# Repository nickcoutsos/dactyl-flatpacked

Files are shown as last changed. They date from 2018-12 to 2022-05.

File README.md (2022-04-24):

# dactyl–flatpacked

A reimagined [dactyl](https://github.com/adereth/dactyl-keyboard) using 2D
slotted pieces instead of 3D printing.

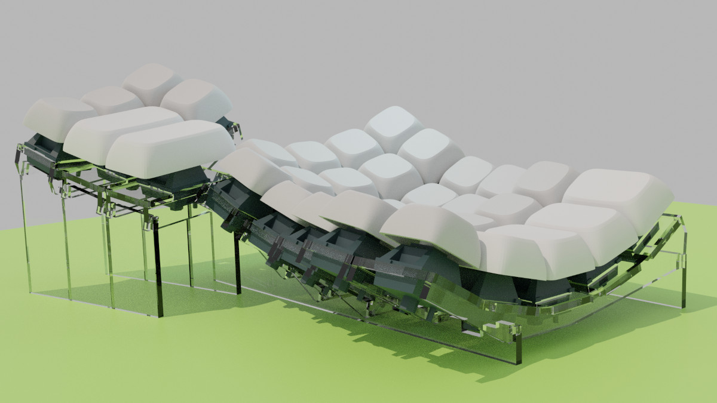
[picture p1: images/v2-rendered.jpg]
Keyboard

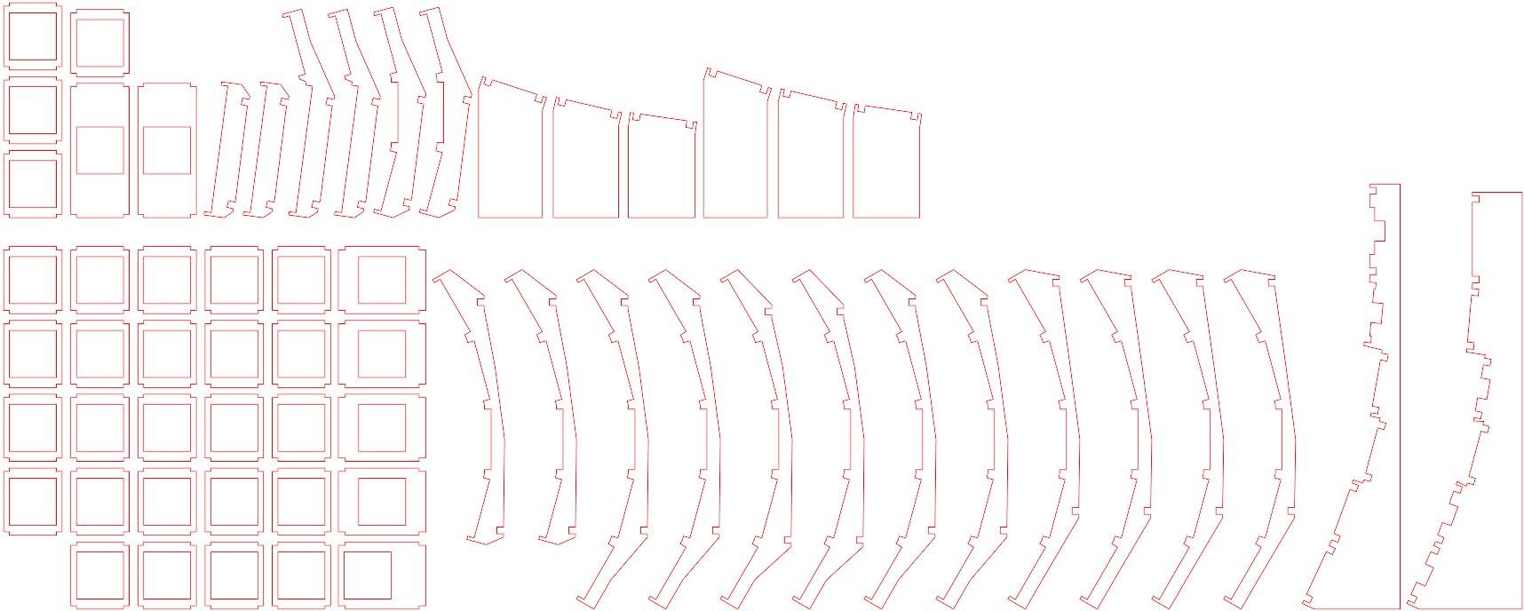
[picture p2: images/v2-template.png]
Cutting template


**Note:** I built this keyboard years ago with code that has since changed
considerably. The current state of the master branch is still a work in progress
and hasn't been tested. I don't have immediate plans to build a new keyboard
from this design in the near future but the refactor and redesign is a fun
project anyway, and hopefully of some use/interest to you.

If you want to see the original code and cutting template look at the tag
`original`.

## The Idea

Use two dimensional pieces of laser cut acrylic, slotted together orthogonally,
to create the Dactyl keyboard shape.

When I started this project the cost to have a Dactyl printed by a third party
seemed prohibitively expensive and the printer I had access to was not up to the
challenge. Neither of these restrictions are true today but this was pretty fun
to work on anyway.

## Recent Changes

This iteration still makes the Dactyl keyboard shape but there are significant
differences:

1. Place column supports on either side of the switch instead of beneath it.
    This requires thinner material but the original 3mm of acrylic was already
    more than thick enough. The current design is 2mm and things seem to fit
    together nicely.
2. Fix the row/column radius calculations to account for keycap height: the
    `mount_width`/`mount_depth` parameters need to reflect the dimensions of the
    keycap at its base in order to get the correct spacing.
3. Construct everything from extruded polygons instead of `hull()`ing and
    `difference()`ing all kinds of geometry. This seems to perform better and
    makes it less weird to try to flatten everything when generating a cutting
    template (which is kind of the whole point anyway).

To simplify the code I've started migrating things over to using the amazing
[BOSL2](https://github.com/revarbat/BOSL2) library.

## See Also

Over time I have seen more designs pop up using similar ideas to build up the
structure of a 3D contoured keyboard using 2D laser cut components. You may be
interested in looking at:

* [Habilis](https://github.com/thblt/habilis) by Thibault Polge
    * Designed in Autodesk Inventor, I think
    * This is the first implementation I saw after my own
    * It seems to have the most in common with the dactyl-flatpacked
    * Pictures available on his reddit posts:
        * [/r/MechanicalKeyboards/comments/cbehge/very_early_preview_my_first_build_a/](https://www.reddit.com/r/MechanicalKeyboards/comments/cbehge/very_early_preview_my_first_build_a/)
        * [/r/MechanicalKeyboards/comments/cm97ey/my_first_build_the_habilis_design_preview_while/](https://www.reddit.com/r/MechanicalKeyboards/comments/cm97ey/my_first_build_the_habilis_design_preview_while/)
        * [/r/MechanicalKeyboards/comments/covxon/first_real_prototype_for_my_split_concave_build/](https://www.reddit.com/r/MechanicalKeyboards/comments/covxon/first_real_prototype_for_my_split_concave_build/)
* [Acrylic 3D KB](https://github.com/kobababa/Acrylic_3D_KB) by Kobakos
    * Designed in Fusion 360
    * I was really impressed by the elegance of this design.
    * It does sacrifice curvature around the Y axis and per-column stagger, but
        I think grouping pairs of columns is a clever compromise and results in
        a much smaller part count.
    * Having fewer and larger pieces would help with assembly and probably makes
        for a less fragile end result.
* [Lasercut modular ergo keyboard with wells](https://www.reddit.com/r/ErgoMechKeyboards/comments/njuay2/second_prototype_of_a_lasercut_modular_ergo/) by [/u/Macone4](https://www.reddit.com/user/Macone4)
    * Designed in Fusion 360
    * Also [the first prototype post](https://www.reddit.com/r/ErgoMechKeyboards/comments/nbbqdz/first_proof_of_concept_of_a_lasercut_modular/)
    * Tighter curvature than the Dactyl, I think
    * First time seeing one of these using wood!
    * Looks to be a similar strategy to the dactyl-flatpacked and Habilis
    * A single support down the center of each column is interesting
        * May allow columns to squeeze in more tightly without interference
        * Looks like this would add to the minimum height due to the extra
            clearance needed underneath the switch
* [Laser cut dactyl](https://www.reddit.com/r/ErgoMechKeyboards/comments/txumq3/laser_cut_dactyl/) by [Rannathrtv](https://www.reddit.com/user/Rannathrtv)
    * Designed in Fusion 360
    * Another wooden design, the end result looks lovely with the burnt edges!
    * Row-based instead of column based, so curvature is around X axis and is
        otherwise ortholinear
    * Far fewer pieces to deal with
    * May have been designed with hotswap sockets in mind
    * Based on images it looks like there is a slight tenting so the row pieces
        don't technically slot in at 90˚. This may not be an issue if everything
        is glued or otherwise held firmly in place.

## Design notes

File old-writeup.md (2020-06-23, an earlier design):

# dactyl–flatpacked

A reimagined [dactyl](https://github.com/adereth/dactyl-keyboard) using slotted
rib pieces to create the countoured surface instead of a solid 3D printed part.

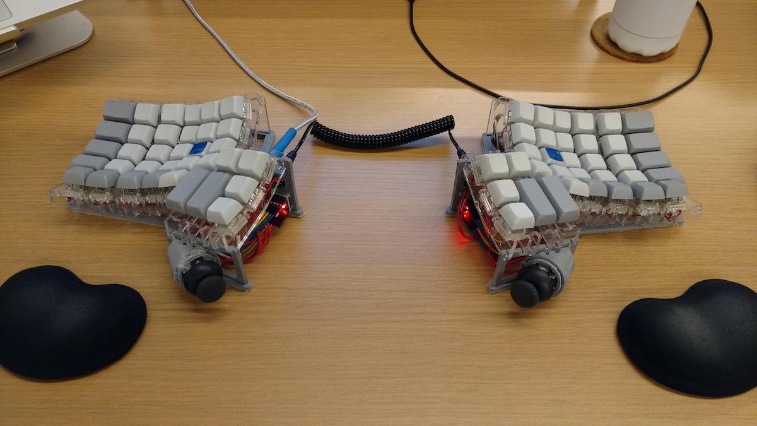
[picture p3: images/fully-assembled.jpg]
Keyboard

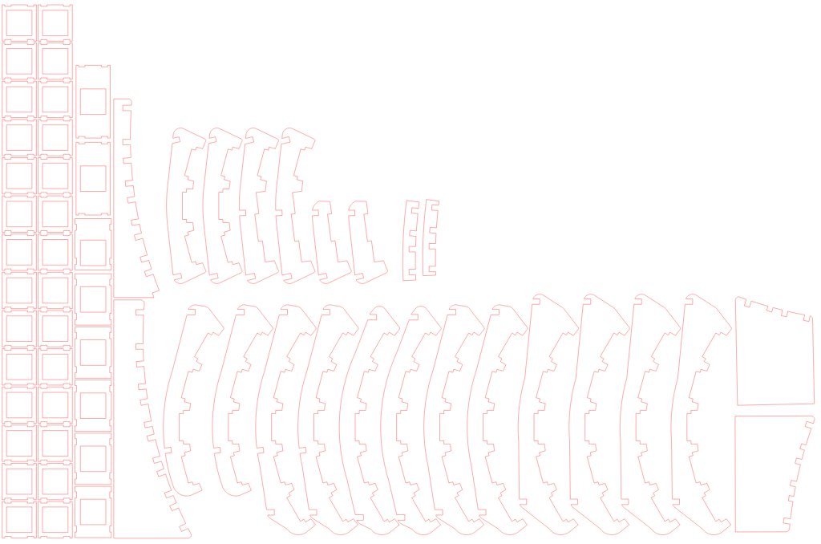
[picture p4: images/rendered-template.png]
Cutting template


**Note:** the current state of the master branch doesn't accurately reflect the
version of the keyboard that I have built. Since then I've started to work on a
low profile version and have refactored most of the code as well as re-designed
the rib pieces and thumb cluster. Check out the tag _original_ to see more or
less the original code used to generate the initial laser cut template.

## Inspiration

When I first head about the dactyl keyboard I had been realizing that my typing
habits have been awful for years despite being able to type quickly and with few
mistakes. The dactyl seemed to address a lot of the problems but seemed like a
big investment to either order quality printed parts or to attempt printing it
myself.

Rather than spend moeny directly on something I may not have actually enjoyed in
the end, I decided to try creating a design that could match the original
contours using many smaller pieces that could be reliably cut from wood or
acrylic. The time to design and assemble the structure myself was likely more
expensive but the experience was invaluable.

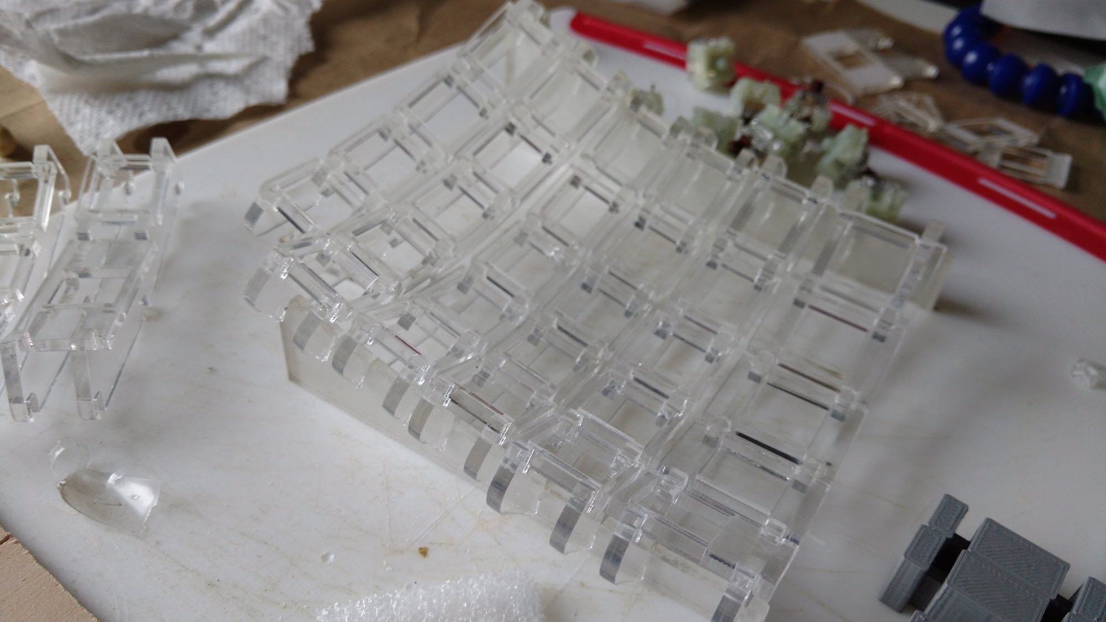
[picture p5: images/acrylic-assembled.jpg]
assembled


## Execution

The first step was rewriting the positioning code in OpenSCAD directly. Clojure
is interesting, OpenSCAD is... flawed, but the pipeline of _lein_ to _clojure_
to _scad-clj_ to _OpenSCAD_ was a lot of trouble and made debugging painful.

Once I had OpenSCAD code that matched the original layout I could throw most of
the rest of the code away; I didn't need to create a 3d printable plate or case
or anything, the rest was from scratch.

I designed curved supports for each column of keys with slots at the front and
back allowing each column to connect to a common front and back row support. The
shorter finger and thumb columns don't reach the row supports and instead use a
small support connecting it directly to the adjacent column.

With the design finished I created another file to import each part rib support,
cross support, an key plate, transformed to be co-planar with the XY plane, and
projected to a number of 2D shapes. I exported the result to SVG from OpenSCAD
and moved to Inkscape to clean up the result before passing along to a local
company for laser cutting.

## Wiring and Programming

> TODO, add more details and pictures here

Wiring was painful. I think I could have gotten away with thinner and shallower
rib pieces that would've made it easier to get in with my soldering iron. My
design included small gaps that I hope would allow me to snake magnet wire along
each row of switches, but that didn't work out. I had the idea to run ribbon
cables down each column to connect the rows in a more convoluted way which was a
mess but it worked. If I did this before gluing all of the columns to the cross
supports I might have had an easier time but overall I think it woulve been
smarter just to run wires across the columns and be done with it.

The firmware wasn't anything terribly special. I copied the dactyl manuform code
from the QMK repo and modified it to match the physical layout of the original
dactyl. This was obnoxious because I had to hardcode changes that ideally could
have been configuration (the physical layout of the dactyl, but the manuform's
use of two pro micros instead of a teensy and IO expander).

## Results

I've been using my dactyl keyboard at work for several months now and quite like
it. The way I describe it to other people is:

> The keys are where my fingers want to be.

It's hard to say how much of this is unique to the dactyl design or specifically
which aspects of the design. The main features I'll harp on is column-stagger
instead of row-stagger and, by extension, column depth offsets to match (partly)
different lengths of finger.

A few issues:

### Thumb Cluster

There are keys that I don't really care to reach, which is fine for toggles, I
guess, but I also feel that the 2h keys use up valuable space. It's nice that
there are cheap ergodox keysets readily available to use in my keyboard but if I
were to do it again I'd work on making things more compact.

### Gaps Between Keys

I think this is my own fault. The original dactyl was designed for SA keycaps
which are significantly taller than the XDA profile I chose. This is a problem
because much of the calculations for key positioning are based on the height of
the keys and the height (thickness) of the plate. Taller keys need a higher
radius to fit in the same curve which means my keys end up spaced out. This is
one of the areas where the dactyl code could be better documented.

Unfortunately I'm realizing that had I worked off of the dactyl manuform fork I
might have been able to better understand these details and account for them.
The manuform fork seems to use very clear variable names and introduces even
more for better configurability.

### Height

This is possibly my biggest gripe.

This is kind of the nature of the beast of a non-flat keyboard layout. With the
degree of curvature and the minimum height for the lowest keys (this includes
the combined height of the keycap and keyswitch, down to the electrical contacts
underneath) you end up with a keyboard that is significantly taller than, say, a
typical Apple bluetooth keyboard. On top of my desk I need to raise my wrists
quite a bit so that my hands can hang downward. A better solution is to put the
keyboard on a lowered tray, or make sure your chair can be comfortably raised
high enough to compensate.

## Next Up

I'm working on a redesign using kailh low profile switches and keycaps, with a
reduced curvature on the main cluster. This should help keep the keyboard height
reasonable. It also redesigns the thumb cluster using 1u keys and increases the
curve so that the innermost keys end up being more vertical, hopefully making
the outer thumb columns easier to reach.

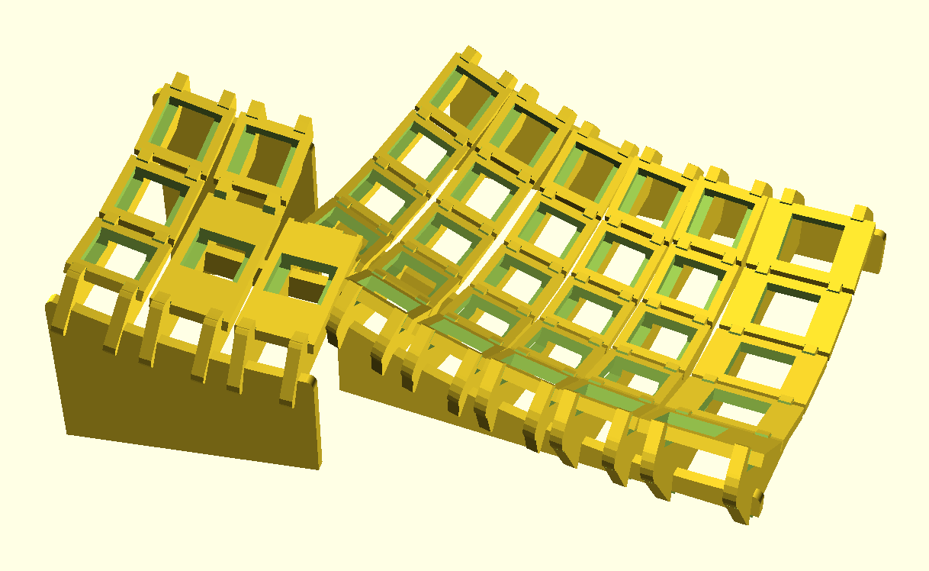
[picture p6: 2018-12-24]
images/rendered-frame.png

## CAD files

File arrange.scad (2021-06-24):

include <BOSL2/std.scad>

function calculate_bounding_box (points_or_region) = (
  let(points = (
    is_path(points_or_region[0])
      ? flatten(points_or_region)
      : flatten(flatten(points_or_region))
  ))
  let(x = [ for(v=points) v.x ])
  let(y = [ for(v=points) v.y ])
  let(min_ = [min(x), min(y)])
  let(max_ = [max(x), max(y)])
  [min_, max_, max_ - min_, (max_ + min_) / 2]
);

function arrange(regions, direction="row", spacing=0, align_items="center") = (
  assert(direction == "row" || direction == "row-reverse" || direction == "column" || direction == "column-reverse")
  assert(align_items == "center" || align_items == "start" || align_items == "end")
  let(bounding_boxes = [ for(r=regions) calculate_bounding_box(r) ])

  let(is_reversed = direction == "row-reverse" || direction == "column-reverse")
  let(is_row = direction == "row" || direction == "row-reverse")

  let(main_axis_component = is_row ? 0 : 1)
  let(main_axis = (is_row ? [1, 0] : [0, 1]))
  let(main_length = sum([
    for(box=bounding_boxes)
    box[2][main_axis_component]
  ]) + spacing * (len(regions)-1))

  let(cross_axis_component = is_row ? 1 : 0)
  let(cross_axis = is_row ? [0, 1] : [1, 0])
  let(cross_length = max([
    for(box=bounding_boxes)
    box[2][cross_axis_component]
  ]))

  let(total_bounding_box = (
    main_axis * main_length +
    cross_axis * cross_length
  ))

  flatten([
    for(i=[0:len(regions)-1])
    let(paths = regions[i])
    let(size = bounding_boxes[i][2])
    let(center = bounding_boxes[i][3])
    let(prev_group_sizes = i == 0 ? 0 : sum([
      for(j=[0:max(0, i-1)])
      bounding_boxes[j][2][main_axis_component] + spacing
    ]))
    let(main_offset = (
      (size/2)[main_axis_component]
      - (total_bounding_box/2)[main_axis_component]
      + prev_group_sizes
    ))

    let(cross_offset = align_items == "center" ? 0 : (
      (align_items == "start" ? -1 : 1) * (
      (size/2)[cross_axis_component]
      -(total_bounding_box/2)[cross_axis_component]
    )))
    let(offset_ = -center - (cross_axis * cross_offset) + main_axis * (
      is_reversed
        ? total_bounding_box[main_axis_component] - main_offset
        : main_offset
    ))
    [ for(path=paths) move(offset_, path) ]
  ])
);

/**
 * Arrange regions using a CSS flexbox-like rules.
 *
 * Some terminology first:
 *  - a path is an array of vertices ([ [x, y], ... ])
 *  - a region is an array of paths ([[ [x, y], ... ]])
 *
 * This module will arrange and render regions along an axis with the specified
 * alignment and spacing.
 *
 * Given a direction of "row" these regions will be laid out end-to-end (plus
 * "spacing" between eeach) on a "main-axis" going from left to right (x-axis),
 * and vertically aligned on the "cross-axis" (y-axis). Specifying "column" will
 * swap the main and cross axes. Including "-reverse" will lay the regions out
 * in reverse order on the main-axis.
 *
 * By default, regions will be centered on the cross-axis, but can be aligned to
 * the low or high end of the overall bounding box by settign align_items to
 * "start" or "end" respectively.
 *
 * Lastly "anchor" can be used to shift the origin relative to the regions'
 * overall bounding box.
 *
 * These arrangements may also be nested by supplying an array of arrange()'d
 * values.
 *
 * @param <array> regions
 * @param <string> [direction="row"] - one of (row|row-reverse|column|column-reverse)
 * @param <number> [spacing=0] - spacing between bounding boxes of regions
 * @param <string> [align_items="center"] alignment on cross-axis
 * @param <vector[x,y]> anchor
 */
module arrange(regions, direction="row", spacing=0, align_items="center", anchor=[0, 0]) {
  assert(direction == "row" || direction == "row-reverse" || direction == "column" || direction == "column-reverse");
  assert(align_items == "center" || align_items == "start" || align_items == "end");

  arranged = arrange(
    regions,
    direction=direction,
    spacing=spacing,
    align_items=align_items
  );

  box = calculate_bounding_box(arranged);
  size = box[2];
  center = box[3];

  offset_ = [
    -anchor.x * size.x/2,
    -anchor.y * size.y/2
  ];

  translate(-center + offset_)
    region(arranged);
}

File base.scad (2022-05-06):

use <supports.scad>
use <util.scad>
include <definitions.scad>
include <BOSL2/beziers.scad>

// Using `cross_support_bottom_points()` can give us all of the contact points
// of a cross support on the XY plane. From this we can define the paths to cut
// holes out of a base for the keyboard.
//
// What this function actually returns is the bottom profile of a cross support
// which includes the new corner notch cutouts, so the "true" bottom points are
// just the ones where p.z == 0. This does assume that the cross support will
// only have cutouts in the corner, so that the remaining points will be the
// start and end points of the cross support.

xy = function (p) [p.x, p.y];
is_base = function (p) p.z == 0;

thumb_back = [for(i=[0:len(thumb_columns)-1]) map(xy, filter(is_base, cross_support_bottom_points("thumb", "back", i)))];
thumb_front = [for(i=[0:len(thumb_columns)-1]) map(xy, filter(is_base, cross_support_bottom_points("thumb", "front", i)))];
thumb_points = concat(thumb_back, thumb_front);

finger_back = map(xy, filter(is_base, cross_support_bottom_points("finger", "back")));
finger_front = map(xy, filter(is_base, cross_support_bottom_points("finger", "front")));
finger_points = [finger_back, finger_front];

cross_support_holes = [
  for(line=concat(
    thumb_back,
    thumb_front,
    [finger_back,
    finger_front]
  ))

  thicken_line(line, plate_thickness)
];

function inner_round (points, r) = (
  let(inset = offset(points, closed=true, r=-2*r))
  offset(inset, closed=true, r=r)
);

finger_cluster_cutout = inner_round(hull_points(flatten(finger_points)), r=4);
thumb_cluster_cutout = inner_round(hull_points(flatten(thumb_points)), r=4);

outline = concat(
  [finger_back[1]],
  bezier_curve(flatten([
    bez_begin(finger_back[0], 270, 80),
    bez_end(thumb_back[2][0], 0, 0),
  ])),
  [thumb_front[2][0]],
  bezier_curve(flatten([
    bez_begin(thumb_front[0][1], 0, 0),
    bez_end(finger_front[1], 180, 90),
  ]))
);

module base() {
  linear_extrude(height=plate_thickness)
  region(concat(
    [offset(outline, r=4, closed=true)],
    cross_support_holes,
    [finger_cluster_cutout, thumb_cluster_cutout]
  ));
}

color("red") stroke(cross_support_holes, width=0.25, joint_width=0, hull=false);
color("red") stroke(finger_cluster_cutout, width=0.25, joint_width=0, closed=true, hull=false);
color("red") stroke(thumb_cluster_cutout, width=0.25, joint_width=0, closed=true, hull=false);
color("yellow", alpha=0.3) base();

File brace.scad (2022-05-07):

include <BOSL2/std.scad>
include <BOSL2/beziers.scad>
include <definitions.scad>
use <supports.scad>

xy = function (p) [p.x, p.y];
is_base = function (p) p.z == 0;

thumb_back = [for(i=[0:len(thumb_columns)-1]) map(xy, filter(is_base, cross_support_bottom_points("thumb", "back", i)))];
thumb_front = [for(i=[0:len(thumb_columns)-1]) map(xy, filter(is_base, cross_support_bottom_points("thumb", "front", i)))];
thumb_points = concat(thumb_back, thumb_front);

finger_back = map(xy, filter(is_base, cross_support_bottom_points("finger", "back")));
finger_front = map(xy, filter(is_base, cross_support_bottom_points("finger", "front")));
finger_points = [finger_back, finger_front];


function thumb_outer_column_end() = (
  let(
    u = plate_thickness,
    col = thumb_back[2],
    a=col[0],
    b=col[1],
    v=unit(b-a),
    n=line_normal(col)
  )
  [
    a + n*u/2 - v*u,
    a - n*u/2 - v*u,
  ]
);

function thumb_columns () = (
  flatten([
    for (col=reverse(thumb_back))
    let(
      u = plate_thickness,
      a = col[0],
      b = col[1],
      v = unit(b-a),
      n=line_normal(col)
    )
    [
      a - n*u/2,
      a + n*u/2,
      b + n*u/2,
      b - n*u/2,
    ]
  ])
);

function thumb_inner_column_end() = (
  let(
    u = plate_thickness,
    col = thumb_back[0],
    a=col[0],
    b=col[1],
    v=unit(b-a),
    n=line_normal(col)
  )
  [
    b - n*u/2 + v*u,
    b + n*u + v*u
  ]
);

function finger_front_slot() = (
  let(
    finger = finger_front,
    u = plate_thickness,
    p = finger[0],
    v = unit(finger[1] - finger[0]),
    n = line_normal(finger)
  )
  [
    p - n * u/2 + v * 10,
    p - n * u/2,
    p + n * u/2,
    p + n * u/2 + v * 4
  ]
);

function finger_back_slot() = (
  let(
    u = plate_thickness,
    finger = finger_back,
    p = finger[0],
    v = unit(finger[1] - finger[0]),
    n = line_normal(finger)
  )
  [
    p - n * u/2 + v * 4,
    p - n * u/2,
    p + n * u/2,
    p + n * u/2 - v * u,
  ]
);

function finger_to_thumb_curve() = (
  let(
    u = plate_thickness,
    thumb = thumb_back[2],
    tp = thumb[0],
    tv = unit(thumb[1] - thumb[0]),
    tn = line_normal(thumb),
    finger = finger_back,
    fp = finger[0],
    fv = unit(finger[1] - finger[0]),
    fn = line_normal(finger)
  )
  bezier_curve(flatten([
    bez_begin(fp + fn * u/2 - fv * u, 270, 80),
    bez_end(tp + tn * u*2 - tv * u, 0, 0),
  ]))
);

module brace() {
  linear_extrude(height=plate_thickness)
  region(
    concat(
      thumb_outer_column_end(),
      thumb_columns(),
      thumb_inner_column_end(),
      finger_front_slot(),
      finger_back_slot(),
      finger_to_thumb_curve()
    )
  );
}

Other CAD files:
debug-helpers.scad
definitions.scad
finger-cluster/definitions.scad
key-layouts.scad
placeholders.scad
positioning.scad
preview.scad
shape-profiles.scad
supports.scad
switch-and-keycap-specs.scad
template.scad
thumb-cluster/positioning.scad
thumb-cluster/supports.scad
util.scad

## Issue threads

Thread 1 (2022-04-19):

Optimize rendered SVG

nickcoutsos, 2022-04-19:
> laser cut acrylic is expensive, and printing two copies is twice the price of printing one copy. So if you could bring both halves into one svg file and minimise wasted space, this would be a lot cheaper to print an entire keyboard.

The SVG shown in the repo can certainly be used as a cutting template as-is, but it hasn't been optimized. I mainly wanted to illustrate the output of this codebase: 2D geometry.

Optimization is an interesting problem, and not entirely straightforward. I see two types of optimization:

1. Reducing the amount of material used
2. Reducing the amount of cutting required

The first kind of speaks for itself. I think the keyboard I built in 2018 cost somewhere shy of 100 CAD to cut, and now that we're entering year three of a pandemic I don't know if acrylic is getting any cheaper. The fewer parts we have to cut, the better. The more optimally we pack those parts, the more we can get out of a single sheet of acrylic. There are complications to this: the service I went to charged for a minimum sized sheet that was already more than I needed for... probably two full keyboards. But different services will have different constraints, and some may even let you supply your own material.

The second one kind of builds on the "cut less stuff if you can" idea and throws in curveballs like making edges of different pieces touch wherever possible so that they share cut lines. This one I can't actually do before rendering the SVG or else OpenSCAD would combine them into one larger path.

Another aspect is customization. I pre-rendered the cutting template for a 6x5 dactyl with the 1.5u + 1u outer column because it was easier to get a cheap set of Ergodox keycaps, but I know that's not for everyone. I don't even use a number row these days.

All this to say, some of the optimization will have to happen on the end user's side. I'm not against implementing some that I can, though I'll be relying heavily on third party libraries (I'm looking at [SVGnest](https://github.com/Jack000/SVGnest) so far but that solves problem one, not problem 2).

7t2, 2022-04-20:
/u/priornextgen here
I definitely agree with reducing the amount of material used, i.e. minimising wasted space. However I cant say I agree with reducing the amount of cutting required. I enjoy having the numbers row and minimising the amount of shortcuts needed to remember. Plus, I think trying to minimise the amount of cutting would take a lot of time and energy, and I don't think it would be worth it.

nickcoutsos, 2022-04-20:
Suppose you have 4 equally sized squares to cut out. You can squeeze them close together so that they efficiently use up the available material and save on space, but I'm talking about something else. In the normal cause you would make 16 cuts: one for each side of each square. Alternatively, you could bunch up each of the squares and make only 6 cuts because 8 of the square edges are shared by other squares and therefore don't need to be cut again.

```
 _    _
|_|  |_|

 _    _
|_|  |_|
```

vs

```
 _._
|_|_|
|_|_|
```

If you're only interested in the space optimization you can pass the SVG through a tool like SVGnest

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

7t2, 2022-04-20:
Well if the method you're talking about takes into consideration the width of the laser, then I think that is a great idea. I understand what you mean now, awesome idea. That will save quite a bit on cost

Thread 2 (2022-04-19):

Spare parts

nickcoutsos, 2022-04-19:
> flimsy handling may break some of the smaller pieces, so an extra 1u key holder or two would be appreciated.

This can be easily arranged. Would this be better as a separate SVG that a user can add on or included in the the "default" template.

7t2, 2022-04-20:
Great idea having it as an optional seperate SVG. However, once you have optimised the cutting template to minimise wasted space, if you can fit an extra 1u key holder, I don't see why there shouldn't be an extra one put in there.

Its very easy to snap one by accidentally placing your arm on it, or if you accidentally glue down the wrong sides it is easier to try again with a new one rather than wipe the glue off, because depending on the glue used it could fog the acrylic or attract dust and debris.

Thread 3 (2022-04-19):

Connecting base

nickcoutsos, 2022-04-19:
> a base that connects each half of the project together would add significant cost, but would greatly positively impact the sturdiness of the build in the long run, and provide a space to keep the wiring, microcontrollers, and ports etc

This is a good idea as well. Thin pieces can be used just to connect the thumb and finger cluster. Multiple pieces can be attached at different heights to reduce some of the stresses on the acrylic. Alternatively, one big piece that covers the entire footprint should be relatively strong if you're comfortable with the cost.

Speaking of which, this could be an area where people have different preferences so I can see there being value in generating a template for the footprint in addition to a couple of connector options. This way there's room for people to make their own customization in any old vector editor.

7t2, 2022-04-20:
Yes, I was even thinking of making the base out of thicker wood or some other material like that. So having the base seperate to the rest of the build might actually be a pretty good idea.

One benefit of having a base included though, is that you can slot the pieces into it while you glue and assemble the rest of it together, only gluing it to the base once the wiring has been tested. This would be especially useful for the thumb cluster, because it's difficult making sure the legs are parallel and at the right angle all at once.

Or instead of gluing, one could drill holes in the base and the pieces touching the base, so that they could be wired together, providing a strong but removable method of joining the pieces together.

So maybe having two different material optimised SVG's would be best, one with the acrylic bases, and one without. Because I would really enjoy and use the acrylic base, as I'm sure many others would (it's expensive to have the tools necessary to build a nice wooden base), and it would be much more affordable to have them all together in one file to print.

nickcoutsos, 2022-05-15:
I did some work on a base piece a week or two ago and just realized I never shared the progress. This builds on the "joint" idea, cutting out the lower corners of the thumb cross supports so that they can slot into something.

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

The footprint is based on the innermost and outermost columns for the thumb and finger clusters, and uses some bezier curves for aesthetics. The larger cutouts are to minimize material cost but won't be useful for soldering repairs Might be better to use hot glue or another temporary adhesive on the base. Nesting can be used to cut other pieces out of that space, but I may still come up with a variation that doesn't cover the full length of either cluster.

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
A smaller brace piece is used to connect the finger and thumb clusters at a higher point so that the weight of one half won't snap the base when picked up by the other end.

Here's how the cross supports fit in
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
One key difference between this and the original design is how the back cross support extends across the entire thumb cluster in front of the finger cluster's front cross support instead of spanning two thumb columns behind it. The result is that there isn't a convenient place to snake wires connecting the thumb cluster. I'll probably need to leave a cutout in one of the rear cross supports.

The other thing I wanted to get out of the brace is a way to mount the controller board.
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

I thought I'd have more room, but I can't bring the brace up too high do to the finger column supports. I'll figure something out, but I guess I need to account for a TRRS connector for people who would use it with QMK anyway, so there will likely be a third piece sitting across the base and brace pieces. I guess another option is to leave more room on the base piece and lay the electronics down flat (or stacked maybe, since people may need room for a battery). I'm partial to the sideways thing, though, so I'm going to keep thinking about my options.

7t2, 2022-05-17:
Bro, your design for the base and the brace piece is awesome! I'm so excited to see what you've done, it's super functional and looks really damn good! Having the hole in the base to save material by cutting other pieces inside it is a super clever idea, and the brace along with the base completely solves all of the thumb cluster stability issues. Cutting a hole to snake wires would be convenient, and using the brace to mount the controller board like that is a stroke of genius. Keep it up man, you've got me excited and inspired

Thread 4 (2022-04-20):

Combine thumbstands into two pieces

7t2, 2022-04-20:
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

Having the thumbstands as 6 individual pieces makes assembly really difficult. If they could be combined into just two pieces, it would make assembly alot easier and it would save on print space. It's a win win

nickcoutsos, 2022-04-20:
Yeah, this one is pretty unfortunate but I tried for a long time to avoid it. My first dactyl had just the front and back cross supports for the thumb cluster and I ended up cracking a number of pieces (I ended up having to replace them with 3D printed parts). It was modeled in 3D with slot cutouts made from boolean subtractions, and I didn't notice that the cuts weren't actually orthogonal. I later "corrected" it by switching the order of some matrix transformations, but that wasn't right either.

Apologies in advance because I don't think I understand the math well enough to explain it correctly, but I'm going to try.

1. All pieces that slot together need to intersect at 90˚ so that slot can be cut by a laser
2. Cross supports must intersect the XY plane at 90˚ so that they'll sit flat on table.

This seems to be easy for the finger cluster, but the thing that screws up the second requirement is the fact that the Dactyl thumb cluster has a slight rotation on the axis `[1, 1, 0]` (relevant line in [dactyl-flatpacked](https://github.com/nickcoutsos/dactyl-flatpacked/blob/56549649684b9b4ed242cfab8232d149fab0e2cd/positioning.scad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) and the original [dactyl-keyboard](https://github.com/adereth/dactyl-keyboard/blob/e0416e329032b3648a86e53656906702603dbeb0/src/dactyl_keyboard/dactyl.clj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).

I think this is another case where a base piece is needed to hold all the cross supports in place, but other than that I can't think of a way to reduce the number of cross supports here without sacrificing the thumb cluster tilt.

7t2, 2022-04-20:
Mathematics is my major so I understand what you mean. If each tower has slightly more rotation than the last around the (1, 1, 0) axis, then leave the 6 parts individual and give them each a slot into the base to sit into, then you ideally wouldn't need to attach them together with supports.

I guess the joint would be the acrylic analogue of the mortice and tenon joint, I'm not sure how to describe it so I put a little image together. I exaggerated the rotation just for visualisation, but I think we both know what we mean

nickcoutsos, 2022-04-21:
So if I'm understanding the size of the cutouts correctly, the front view of one of those vertical pieces would look like

```
 _  ___  _
//_/  / //
|        |
|        |
|        |
|        |
|        |
|_      _|
  |____|    <-- this is the joint
```

_Very_ rough diagram.

I hadn't given it a lot of thought but I think this will work best due to how close those vertical support are packed.

7t2, 2022-04-26:
That's exactly what I mean, that should provide enough stability for the thumb cluster, but if not, we can cross that bridge when we come to it

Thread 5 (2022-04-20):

Size of 1u switch holders

7t2, 2022-04-20:
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

The 1u switch holders have a very small distance of material in the corners and snap easily, I think it would definitely be nice to add a little bulk if at all possible.

nickcoutsos, 2022-04-20:
Yeah, that's quite narrow. You can only make it so thick before you have to worry about interference. Are you comfortable with keys being spaced out further to accommodate this? It gets particularly hair at the ends of the finger cluster columns due to the curvature which is another drawback to the number row.

7t2, 2022-04-20:
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

I don't think you need to extend the holders out in both directions, only one. The left and right sides are supported by the acrylic below them, so they dont need to be thickened, but the top and bottom of the holders definitely need to be thickened because they overhang the two pieces of acrylic below them, and as a side effect of making them thicker vertically, the corners no longer have such a short distance of plastic holding the sides together. I hope that makes sense, the key holders would be longer up and down, but the cutout is still 14mm x 14mm

nickcoutsos, 2022-04-21:
Oh, I see. Do you think that will be enough? It's an easy change to make, I think I misjudged how little space there was between the plates already. And I suppose we can get away with that cutout being small, it's just there to help with alignment.

nickcoutsos, 2022-04-23:
So updating the profile for the switch plate was very simple and the cutouts from plate to plate look alright, but this may be an issue for the very ends of the column support where the plate sits.
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

That little nub could very easily break off. It's not exactly integral, but I can imagine that the _way_ it breaks off could lead to further damage. There are some options for mitigating that:

1. Leave the nub off if its width falls under some threshold. No risk of damage, but less help with alignment when gluing the plate. If that's OK there's another question of whether or not it makes sense to leave the slot cutouts for that end of those plates. You'd get a maybe cleaner look but then you have to try and distinguish between these very subtly different pieces during assembly (which is already true but somewhat unavoidable).
2. Shorten the nub. The cutouts in the column supports extend from the bottom of the plate to the top but this isn't a specific requirement so much as... it just made sense to do it that way. If it doesn't extend as far up then there's less of a chance for it to snap but it won't look as nice.

I'm inclined to go with option 1 but I'm realizing that there's an extra weird case in the thumb cluster where the innermost column is a single 2u plate, meaning there would be nothing to help with alignment.

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

This suggests that my original fix should be a little more nuanced and only reduce that cutout for smaller plates where it's needed.

nickcoutsos, 2022-04-25:
Hey, so, this is interesting. I was looking back at the photo of your and felt a little confused at the amount of spacing between plates which looked so different and I finally realized that I already made a change for this 😊 (https://github.com/nickcoutsos/dactyl-flatpacked/commit/9f45d5a1363d2c6f8088616c5dee332fc113eb30). Once again I'm sorry this wasn't available to you!

I'm going to keep this open and I think there's some value to the points discussed above. Even with the extra material these are still pretty dainty so anything that can help with strengthening the plates is worth exploring. I remember reading a long time ago that when cutting corners into acrylic it can be a good idea to cut a tiny circular corner so that there are no sharp edges that can crack from strain. I should look into that again.

7t2, 2022-04-26:
I do think thickening the top and bottom (but not the left and right sides) should be enough. There is plenty of support under the left and right side.

I think that having a small nub at the end is more useful than not, because it allows the person assembling the project to simply push the acrylic together to align everything perfectly, as seen in this photo
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

For the extra weird case, I think it would be best to adjust the support in a similar fashion to what I have drawn here
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

The 1.5u and 2u switch holders, I think they're stucturally sound enough to stay the size they are. But all 1u switch holders definitely need the added material at the top and bottom.

And on that final comment about circular corners, I think by virtue of cutting acrylic with a laser, the corners are already pretty well rounded. If we identify weaknesses in the structure through heavy use, then we might want to think about implementing further crack resistance in those specific points. But until then, the lasered corners seem to do the job well
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

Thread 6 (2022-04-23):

Interference between thumb and finger clusters

nickcoutsos, 2022-04-23:
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

Just noticed this but it seems to have been an existing issue. The second column of the finger cluster is intersecting with thumb cluster column support _and_ plate. One option would be shifting the thumb cluster over a tiny bit, but because it's a small corner of the finger column support's bottom side it may be possible to solve this by rounding/chamfering and keeping true to the original thumb cluster implementation.

7t2, 2022-04-26:
I think it is very important to keep the thumb cluster in its original spot for ergonomic reasons. So we could either alter the design by cutting the corner of the support off, or we could hand file the problem material away during assembly. I think removing a little bit of material shouldn't be too much of a problem, and needing to own a file would add to the total cost of the keyboard
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

nickcoutsos, 2022-04-26:
Definitely in favour of removing the interference in the design. I want to apply the change generically so I'll need to make sure I'm not removing enough to cause strength issues. Shouldn't be a big problem.

nickcoutsos, 2022-05-03:
I've had a closer look. It doesn't take much work to cut off the corner of the columns, but sadly that isn't enough.

Here's the overlap:

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

Blue is the thumb cluster, red is the finger cluster, and yellow is their intersection. Even cutting a hole into that column of the thumb cluster isn't viable because the intersection goes almost through its entire height.

If I shift the thumb cluster 0.62mm left and 0.62mm forward I can clear it. Here's a couple of images showing the difference:
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

Staying true to the original Dactyl's measurements was a major design goal for this project, but this is a tough one. If the thumb's column support is in that position and a finger cluster has to sit right next to it then my options are limited.

I tried a longer cut out of the finger cluster's column support which lets it clear the thumb cluster, but it looks incredibly fragile.
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

That's a rough experiment, but you can see that I'd have to think through how that applies to the profile of other columns. Technically this only has to work for a single column but I'm not too happy with one-off solutions like that.

7t2, 2022-05-03:
In my opinion I think that you should definitely stay true to the original Dactyl's measurements and not shift the thumb cluster. I also understand the appeal of wanting to apply the change generically so that you are not making changes to one single column support. I believe that in this situation, it is worth it to apply the change to the single column support, even if it breaks symmetry and requires more code to maintain. In regards to the fragility of the little alignment nub, it would be expoxied to the keycap during assembly so I do not think that is much of a problem. The main point of consideration is that the bottom of the switch holder is supported well, which it still will be.

Either that, or you can just require the person assembling the unit to file off the intersecting corner, keeping as much strength as possible. It is a complicated diy project after all, so requiring a file/sandpaper isn't the end of the world.

nickcoutsos, 2022-05-03:
It's not about symmetry so much as the code making sense. More special cases means it's harder to keep track of what's happening and why.

> In regards to the fragility of the little alignment nub, it would be epoxied to the keycap during assembly, so I do not think that it is much of a problem.

No, I'm more worried about the end of the column snapping off either during assembly or during regular use. You have these pieces in 2mm acrylic, what's your feeling about those column pieces at their narrowest?

7t2, 2022-05-04:
There is plenty of strength in the columns, even when pushing directly on the overhanging corners. But when a switch is installed, the weight of the press is distributed more evenly and it feels like there is plenty of extra strength avaliable to remove more material. However, if you wanted to give some extra strength back to the column, you could add some material in a similar method to this
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

nickcoutsos, 2022-05-04:
I'll have to make some other adjustments there so that the columns aren't intersecting the base I'm working on but I should be able to do that as well. Thanks for offering your perspective on this!

7t2, 2022-05-17:
Not a problem at all man, thank you for your time and effort!

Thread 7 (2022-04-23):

Include a jig for helping with assembling columns

nickcoutsos, 2022-04-23:
During assembly of the original dactyl-flatpacked I realized that I left too much clearance between the slot cutouts (the OpenSCAD preview renderer doesn't like co-incident faces in `difference()` operations so I usually oversize the subtracted geometry a bit and forgot to remove that in the final render) which meant nothing fit together solidly. To ensure all of the pieces where properly aligned for gluing I had some 3D printed jigs I came up with.

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
_Two printed pieces to firmly hold column supports in place and parallel to one another. At some point I also had another jig that matched the interior curve of and column and had protrusions that fit into the switch cutouts to ensure their alignment._

Had I planned ahead I could have designed another such jig to be cut from acrylic. One jig for the finger cluster will work for all of the columns since the cross-support slots are all in the same place. This should be true of the thumb cluster as well but I'd rather double check that than be wrong about the math for a third(fourth?) time.

7t2, 2022-04-26:
I think the included pieces serve well enough as a jig, as I've illustrated here in these diagrams
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
So with 5 minute epoxy, this project is already pretty easy to assembly accurately as is. Well, except for the thumb cluster. I think having an acrylic base would make assembling the thumb cluster a lot easier.

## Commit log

2017-11-27 Port clj-scad key-places to plain readable openscad
    [definitions.scad, positioning.scad]
2017-12-02 refactor positioning and definitions
    [definitions.scad, positioning.scad]
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2017-12-02 generate support ribs for each column of main keys
    [right.scad, structures.scad]
2017-12-02 Add thumb support structures
    [right.scad, structures.scad]
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2017-12-02 Fix thumb support ribs
    [structures.scad]
2018-01-07 Add row rib structures
    [structures.scad]
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2018-01-14 Break down rib placement and use variables for rib height
    [definitions.scad, positioning.scad, structures.scad]
2018-01-14 Break layout down and use more positioning modules
    [right.scad]
2018-01-17 Support returning to global rotation after placing at key position
    [positioning.scad]
2018-01-17 Add 3d printed connectors for rib ends
    [right.scad]
2018-01-17 Extend ribs to floor and trim using curve
    [right.scad]
2018-01-18 distinguish between rib thickness and plate thickness
    [definitions.scad, positioning.scad, structures.scad]
2018-01-18 set inner radius of curve level with plate center
    [structures.scad]
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2018-01-18 fix support positioning
    [right.scad]
2018-01-20 narrow distance between support ribs
    [definitions.scad, positioning.scad, right.scad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]
2018-01-20 add notches to fit plate pieces in place on support ribs
    [placeholders.scad]
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2018-01-20 cut corners of rib ends to fit flush with end caps
    [right.scad]
2018-01-30 Replace openscad transforms with computed matrices and explicit multmatrix call
    [hull.scad, linalg.scad, mirror.scad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]
2018-01-30 Add cross supports for inner column and thumb cluster
    [right.scad, util.scad]
2018-02-08 Use separate plate length and height definitions
    [definitions.scad, placeholders.scad, right.scad]
2018-02-08 Fix end caps
    [right.scad]
2018-02-08 Add slits to side supports
    [right.scad]
2018-02-09 Move supports and caps into separate files
    [caps.scad, right.scad, supports.scad]
2018-02-09 Lay supports out in XY plane for cutting template
    [positioning.scad, template.scad, util.scad]
2018-02-14 move column offsets to definitions and fix fan definition
    [definitions.scad, positioning.scad, structures.scad]
2018-02-16 wip: front and back row supports
    [nocaps.scad]
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2018-02-24 Add radius to column ribs (commented out)
    [structures.scad]
2018-02-24 Remove support joints and curves
    [supports.scad]
2018-03-01 Add slots for cross supports
    [supports.scad]
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2018-03-02 Add cross supports for short columns
    [nocaps.scad, positioning.scad, supports.scad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]
2018-03-02 Add column cross supports to template
    [template.scad]
2018-03-03 Fix support ends
    [structures.scad, supports.scad]
2018-03-03 Add plates to template
    [placeholders.scad, template.scad]
2018-03-03 Correct for positioning of key vs positioning of top of key plate
    [definitions.scad, positioning.scad]
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2018-03-08 switch to individual (and toggleable) projections
    [template.scad]
2018-04-14 trim bottom of middle columns
    [supports.scad]
2018-04-14 fix thumb support slot positioning
    [supports.scad]
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2018-06-11 jigs to help align pieces during assembly and gluing
    [jig.scad]
2018-06-11 base pieces to connect thumb and finger cross supports
    [connectors.scad]
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2018-06-21 Add clearances
    [stick-attachment.scad]
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2018-10-05 Remove nonsense height offset
    [definitions.scad, positioning.scad]
2018-10-05 shorter keyboard with less drastic curve using kailh lowprofile switches and caps
    [definitions.scad, nocaps.scad, placeholders.scad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]
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2018-10-11 Correct some of the postioning angle calculation
    This was wrong from the beginning and made adjustments to key angles awkward.
    [positioning.scad]
2018-10-11 reduce curvature and key spacing
    [definitions.scad]
2018-10-11 Remove corner rounding from column ribs
    [structures.scad]
2018-10-11 refactor positioning of front slot geometry
    [positioning.scad, supports.scad]
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2018-10-12 remove more unused (?) modules
    [supports.scad]
2018-10-12 play around with slot positioning
    [definitions.scad, positioning.scad, supports.scad]
2018-10-13 move front support back to align with shorter inner column
    [definitions.scad, positioning.scad, supports.scad]
2018-10-16 Add thumb slot positioning and lower thumb cluster
    [positioning.scad]
2018-10-16 thumb column slot positioning
    [supports.scad, util.scad]
2018-10-19 Refactor thumb and finger key clusters
    [assembled-key.scad, caps.scad, definitions.scad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]
2018-10-19 refactor layouts and key placement definitions
    [definitions.scad, layout.scad, positioning.scad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]
2018-10-20 Use finger column definitions in support modules
    [definitions.scad, right.scad, supports.scad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]
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2018-11-01 add detail toggle to simplify preview when developing
    [placeholders.scad, positioning.scad, right.scad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]
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2018-12-24 Shorten rib height and lower keyboard
    [definitions.scad, positioning.scad]
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2021-05-31 Use thinner material so that column supports can be shorter
    [definitions.scad, positioning.scad, right.scad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]
2021-06-01 Re-implement cross supports as polygons instead of hulled cubes
    [positioning.scad, right.scad, shape-profiles.scad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]
2021-06-02 Construct all column supports (including cross support slots) via polygons instead of subtraction
    [definitions.scad, positioning.scad, supports.scad]
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2021-06-02 Fix thumb col/row radius misnaming
    [definitions.scad, jig.scad, positioning.scad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]
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2021-06-03 Update column_support() to work for both thumb and finger keys
    [supports.scad]
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2021-06-05 Make cross supports into functions to return polygon vertices
    [supports.scad]
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2021-06-07 Fix rotation_down
    [debug-helpers.scad, util.scad]
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2021-06-07 Avoid difference in mx_switch placeholder
    [placeholders.scad]
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2021-06-08 Remove scad-utils, add script to clone BOSL2 if needed
    [hull.scad, linalg.scad, mirror.scad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]
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2021-06-13 Fix plate slots
    [shape-profiles.scad]
2021-06-15 Going to silly lengths to sort of support ergodox keyset's outer column
    [definitions.scad, key-layouts.scad, placeholders.scad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]
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2021-06-17 Simplify arrange() to work on a single array of regions
    [arrange.scad, template.scad]
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2021-06-18 Half assed SA keycap copy/pasted from my half assed xda implementation
    I don't own any of these so the measurements may well be completely wrong
    [placeholders.scad, switch-and-keycap-specs.scad]
2021-06-20 Sloppy code to cut switch shape out of cross support slot profile
    [shape-profiles.scad, supports.scad, util.scad]
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2021-06-21 Refactor code to determine which row has the column support slots
    [supports.scad]
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2021-07-06 Increase plate height to mitigate weak point near slot cutout
    [definitions.scad]
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2022-05-04 Update BOSL2 and fix some function calls
    [positioning.scad, supports.scad]
2022-05-05 Refactor cross support bottom points into another function and cut out corner notches
    [supports.scad]
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2022-05-06 Use beziers to cut down on material joining finger and thumb cluster bases
    [base.scad]
2022-05-07 A brace to support the finger and thumb clusters' connection
    [brace.scad]
